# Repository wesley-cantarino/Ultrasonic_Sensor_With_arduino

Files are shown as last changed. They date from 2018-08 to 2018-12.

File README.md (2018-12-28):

## Ultrasonic Sensor With arduino

Este projeto marca a minha transição entre projetos físicos para software pois depois desse projeto eu passei a interessar muito mais na área de programação. Foi aqui que eu conheci uma das melhores linguagens de programação, [Processing <3.](https://processing.org/)

Obs: a documentação encontra-se dentro das pastas do respectivo ano.

## 2017

#### Começo

Precisava fazer um trabalho final para curso de programação física codeIOT. Pensando nisso, eu já estava trabalhando a vários dias  na tentativa de fazer um carrinho de controle remoto (mais tarde descobri que as baterias que eu estava usando e também o transmissor são de baixa qualidade). Visto que não ia conseguir terminar devido a problemas técnicos (hehe). Resolvi então partir para radar ultrassônico.

#### Motivação

Inspirado [neste projeto (how to mechatronics )](http://howtomechatronics.com/projects/arduino-radar-project/) resolvi criar a minha própria versão mas usando 2 ultrassônico.

Realmente ficaram muito parecidos:
* how to mechatronics
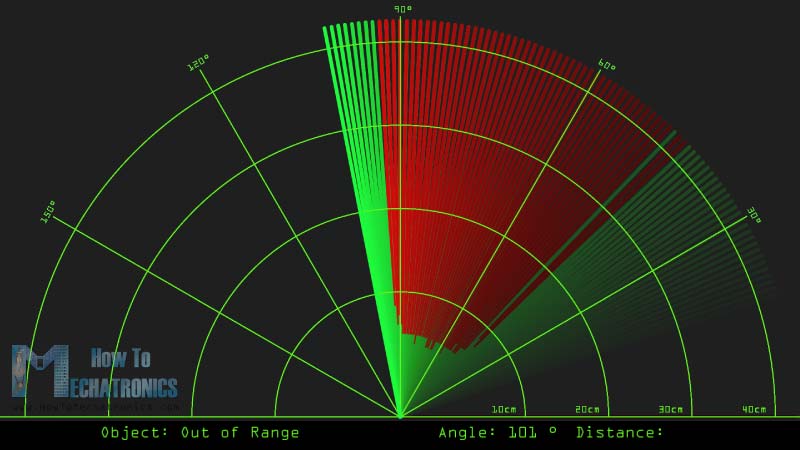
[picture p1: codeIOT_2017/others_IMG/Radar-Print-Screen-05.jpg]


* Minha versão
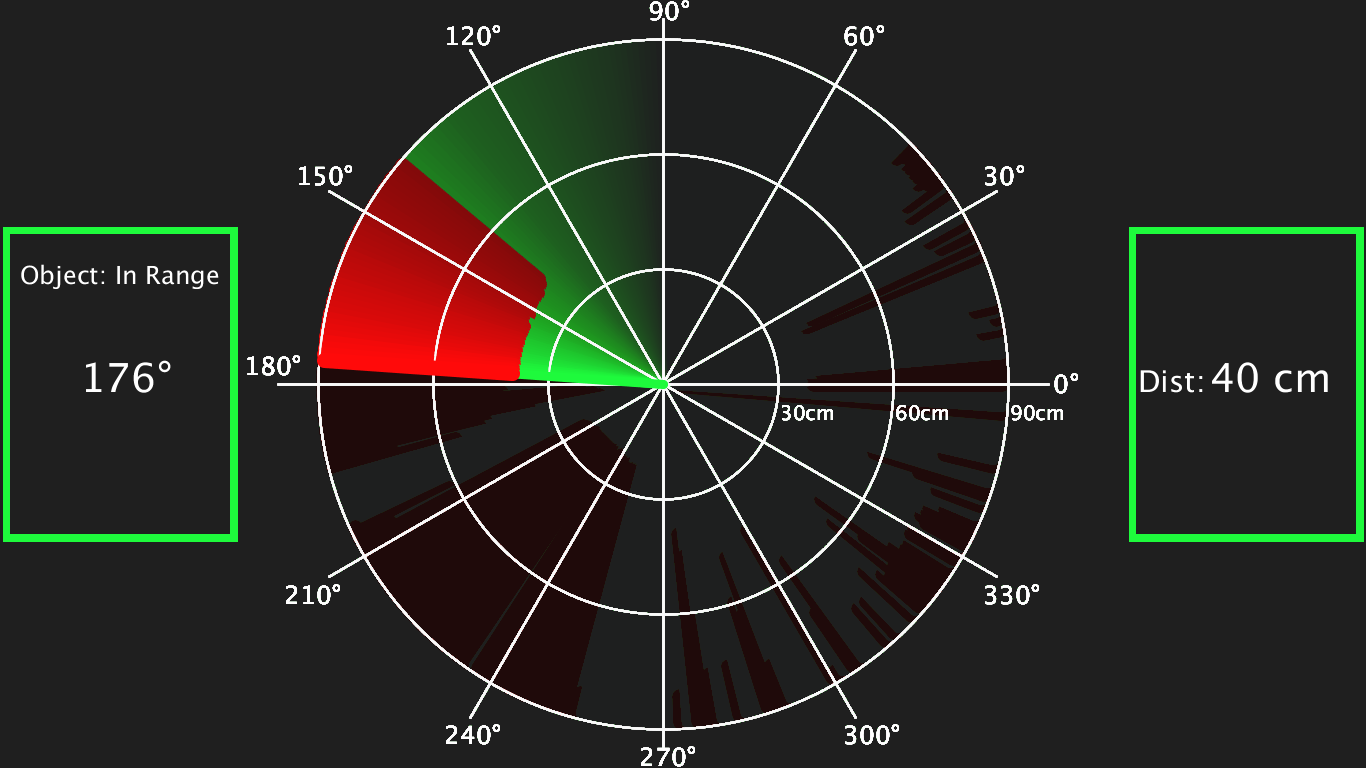
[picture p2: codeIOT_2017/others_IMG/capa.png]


Foi neste projeto que passei a estudar Processing mais a sério.

## 2018

Agora, o foco foi em software. A comunicação sem fio foi retirada e oque antes era em um disco (ou seja, no plano) agora em no IR^3 (ou seja, no espaço tridimensional).

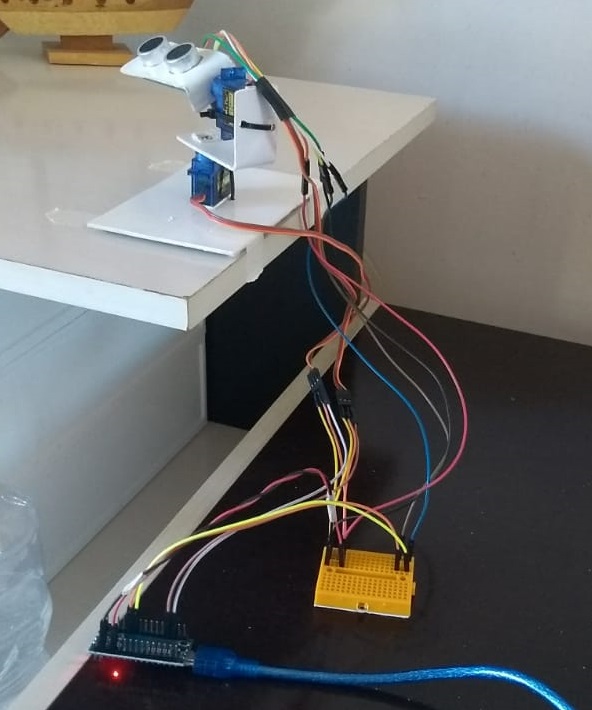
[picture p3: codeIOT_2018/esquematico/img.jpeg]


Menu principal do programa

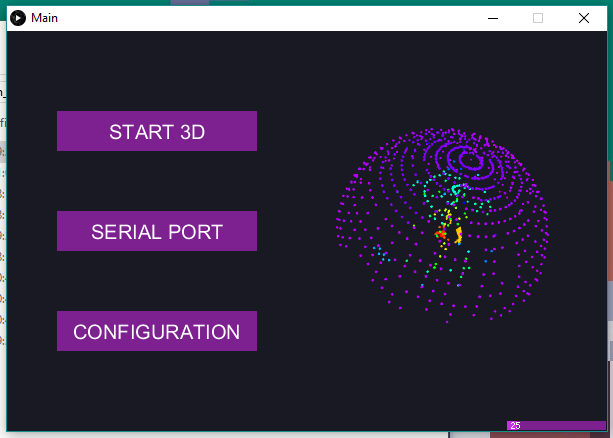
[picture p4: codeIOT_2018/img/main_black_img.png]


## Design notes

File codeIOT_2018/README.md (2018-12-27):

* Obs: Falta fazer documentação decente pois o arquivo codeIOT_2018.pdf está bem fraquinho.

#### [Certificado :D <3](http://codeiot.org.br/certificates/13802e48f1b748a4ace83a3f53ac93c5)

<hr>

### Explicação rápida


A montagem é simples :)

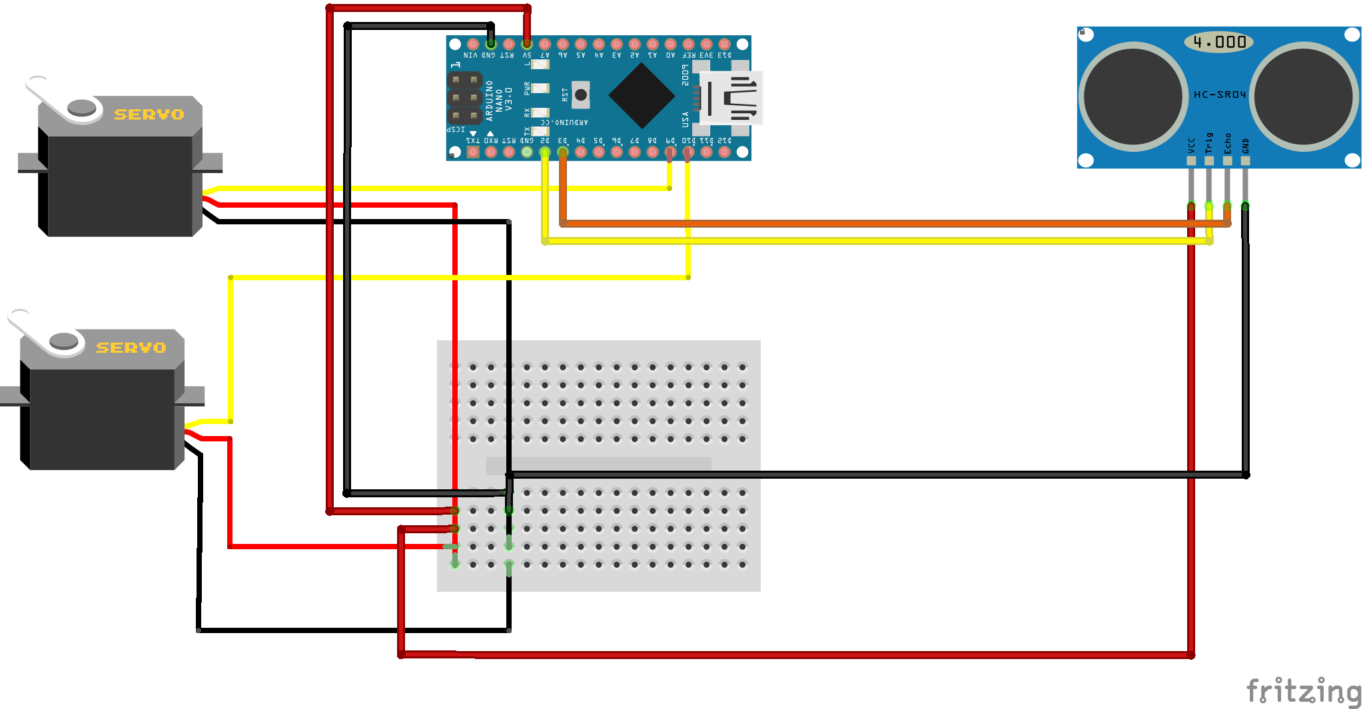
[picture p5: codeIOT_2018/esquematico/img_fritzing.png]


Para quem já estudou mudança de coordenadas na resolução de integrais tripas já sacou que essa montagem é perfeita para coordenadas polares

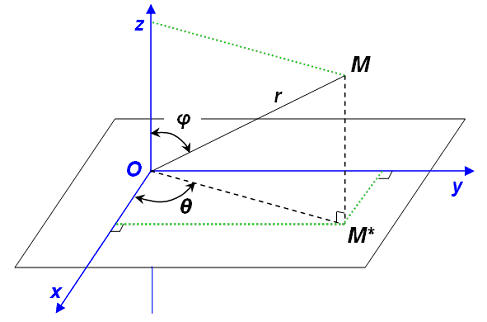
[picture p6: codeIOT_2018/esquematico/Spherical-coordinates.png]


#### Onde
* r é a distancia medida pelo sensor.
* teta e fi são os ângulos dos servos

### Minha tentativa de criar interface gráfica para usuário :D

Menu principal:
 


Temos também o tema claro (essa cor se aplica a todas as outras abas):

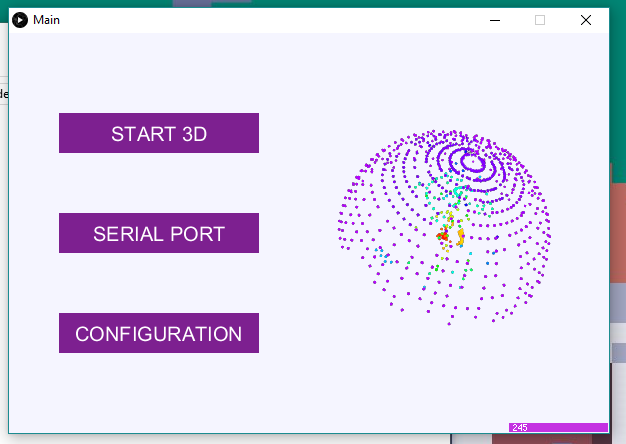
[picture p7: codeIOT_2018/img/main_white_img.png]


<hr>
Aba Configurações 

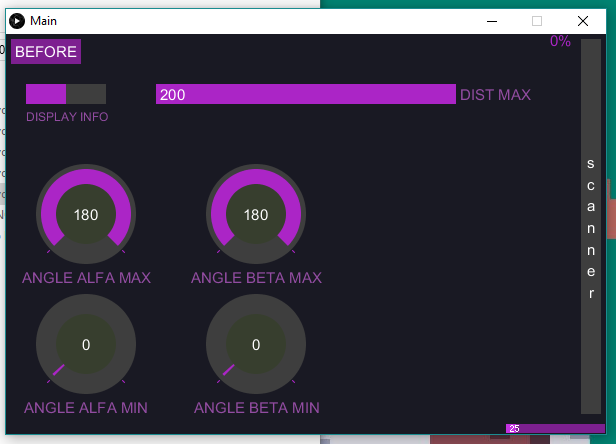
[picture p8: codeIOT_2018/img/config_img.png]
Configurações


<hr>
Aba seleção de porta serial

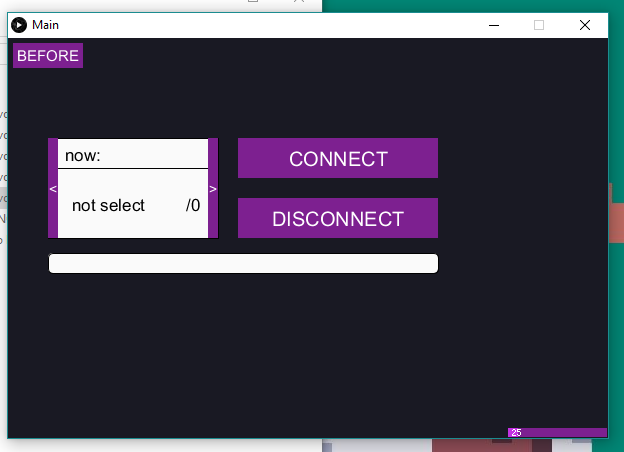
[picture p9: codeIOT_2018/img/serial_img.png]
porta serial


<hr>
* Certamente esse projeto foi de maior complexidade. Perceba a evolução de um ano para o outro.

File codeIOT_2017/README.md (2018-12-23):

* ### Em [proj-Sonar.pdf](https://github.com/wesley-cantarino/Ultrasonic_Sensor_With_arduino/blob/master/codeIOT_2017/proj-Sonar.pdf) tempos toda a documentação mais bem detalhada.

* Dentro da pasta RX_files temos imagem do projeto, Fritzing e o code. Mesma coisa para TX_files

* #### [Certificado :D <3](http://codeiot.org.br/certificates/cbcd800a2408466495cf4520fc58f5d8)

<hr>

### Explicação rápida

* #### Tx
São 2 servos motores de rotação de 180º cobindo assim 360º. O sensor ultrassônico faz leitura da distância e o arduino o envia para Rx.
Se chama Tx pois esse sistema envia dados.

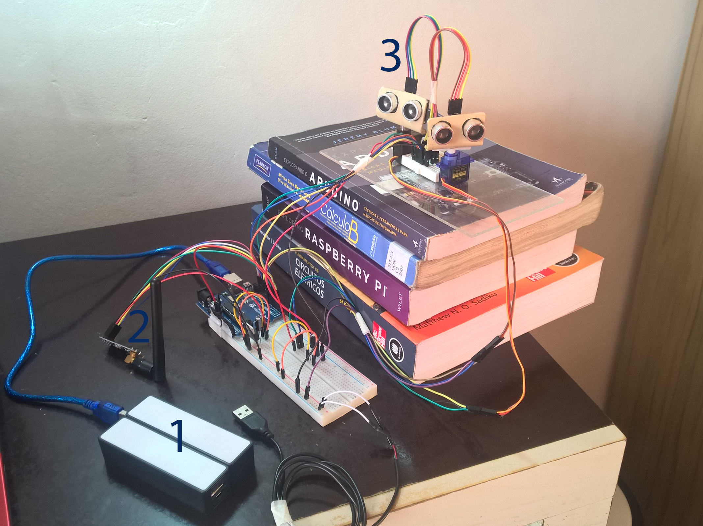
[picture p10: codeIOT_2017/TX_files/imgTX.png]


* #### Rx
Composto por apenas a antena. Esse sistema é responsável por enviar os dados recebido para o computador atravez da porta serial.
Se chama Rx pois esse sistema recebe dados.

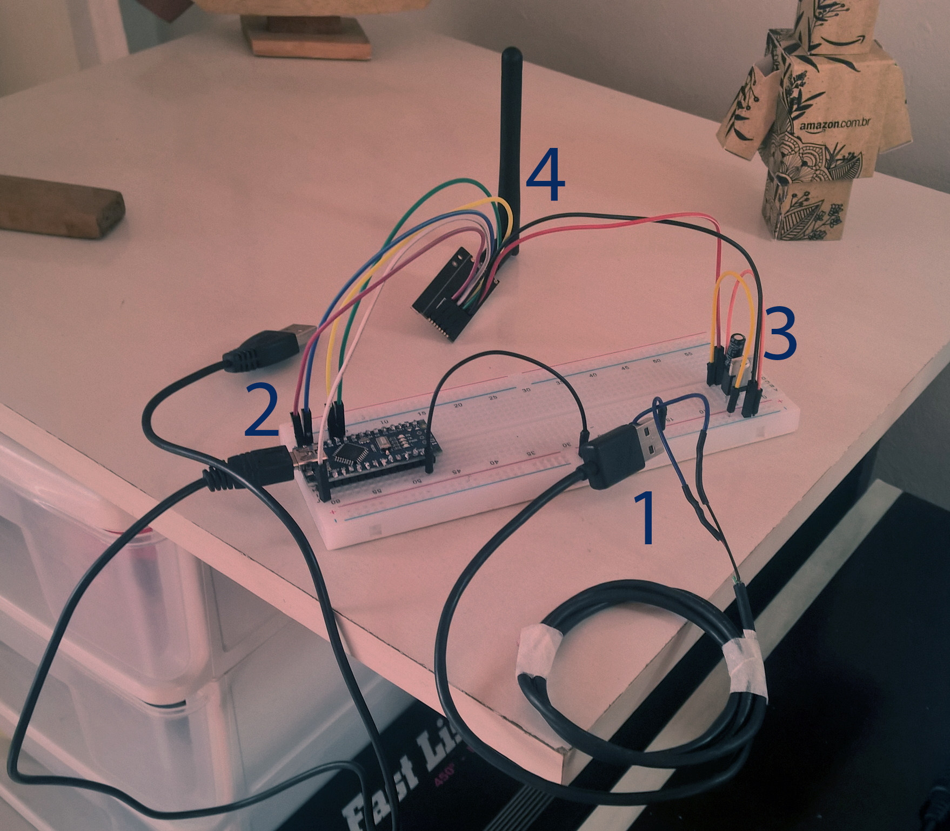
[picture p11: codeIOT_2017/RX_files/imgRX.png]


* #### Processing
Por último o processing vai fazer leitura desses dados na porta serial e vai fazer a parte gráfica. Tendo como resultado isso :)


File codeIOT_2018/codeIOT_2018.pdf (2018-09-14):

# Radar 3D

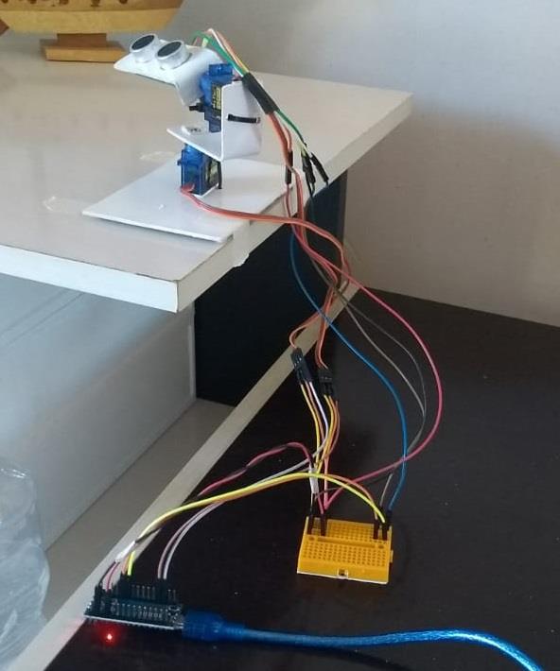
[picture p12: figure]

- Vídeo aqui (vejam pfv): https://youtu.be/GHxOZZLBg7I
- Código aqui: (https://github.com/wesley-cantarino/Ultrasonic_Sensor_With_arduino/tree/master/codeIOT_2018) https://github.com/wesleycantarino/Ultrasonic_Sensor_With_arduino/tree/master/codeIOT_2018
- Não vou apresentar os componentes pois eles já foram apresentados ao longo do curso e também não vou apresentar o código da interface gráfica pois é bem extenso mas para quem tiver curiosidade esta comentado no github.

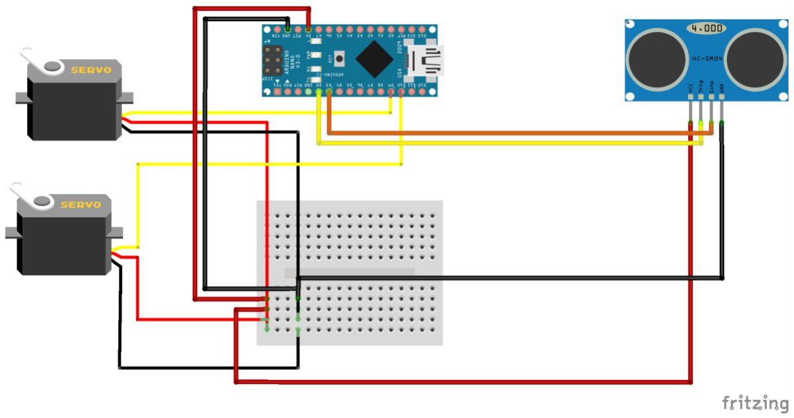
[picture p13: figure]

- Interface gráfica feita com amo <3 usando processing (https://processing.org/).
- A ideia aqui é como gerar imagens de objetos no 3D.
- 2 Servos de 0º a 180º, sensor ultrassônico e arduino nano.
- Coordenada esféricas em cartesianas r é a distância que o sensor ultrassônico medir
0º <= teta <= 180º em relação ao plano XY.
0º <= fi <= 180º em relação perpendicular ao plano XY.

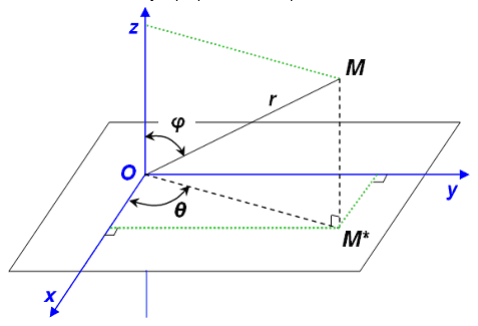
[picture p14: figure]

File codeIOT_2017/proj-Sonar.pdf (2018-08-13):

# SONAR COM ARDUINO

# USANDO IDE PROCESSING E RADIOFREQUÊNCIA

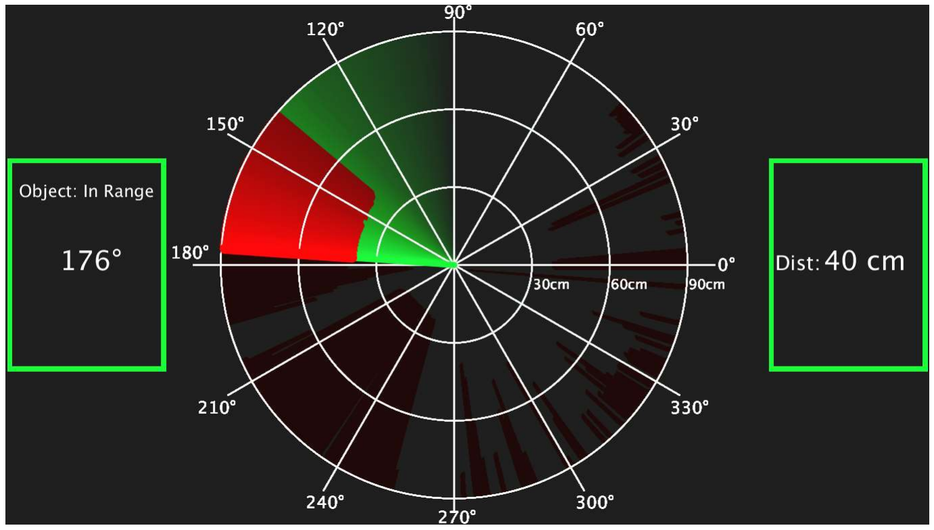
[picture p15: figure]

1

# Sumário

2

# Introdução

O projeto consiste em girar o sensor ultrassônico usando um servo no ângulo de 0 a 180 graus então trocar para o outro servo e girar o outro sensor ultrassônico de 180 a 360 graus totalizando uma volta completa. O ultrassônico tem um alcance de 2 cm a 400 cm mais no processing foi programado para só exibir no “mapa” de 2 cm à 90 cm o motivo dessa escolha foi para não ficar em uma escala muito grande priorizando assim a riqueza de detalhes.
Após o arduino (TX ou seja o transmissor) mover o servo e calcular a distância pelo ultrassônico então chega na melhor parte. A transmissão sem fio! Usando NRF24L01 com antena externa (importante lembrar que este módulo não segue o protocolo IEEE 801.11 então não vai se comunicar com WIFI do roteador ou do celular apesar de trabalhar na mesma frequência). O TX envia a informação (ângulo e distância) o RX (receptor) recebe e envia para o computador através da porta serial. Então os dados são interpretados pelo IDE processing que move a barra verde e desenha a barra vermelha de acordo com o ângulo e a distância recebida. Link para o vídeo mostrando o projeto: https://www.youtube.com/watch?v=B4Q-fz4psLs

# Montagem

## Imagem do RX (receptor):

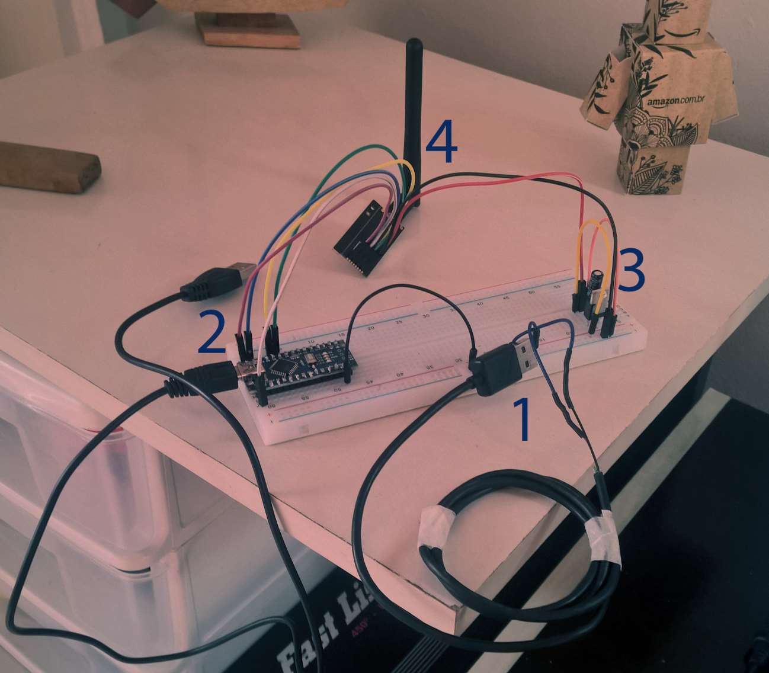
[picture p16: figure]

## Esquema de ligação usando o fritzing:

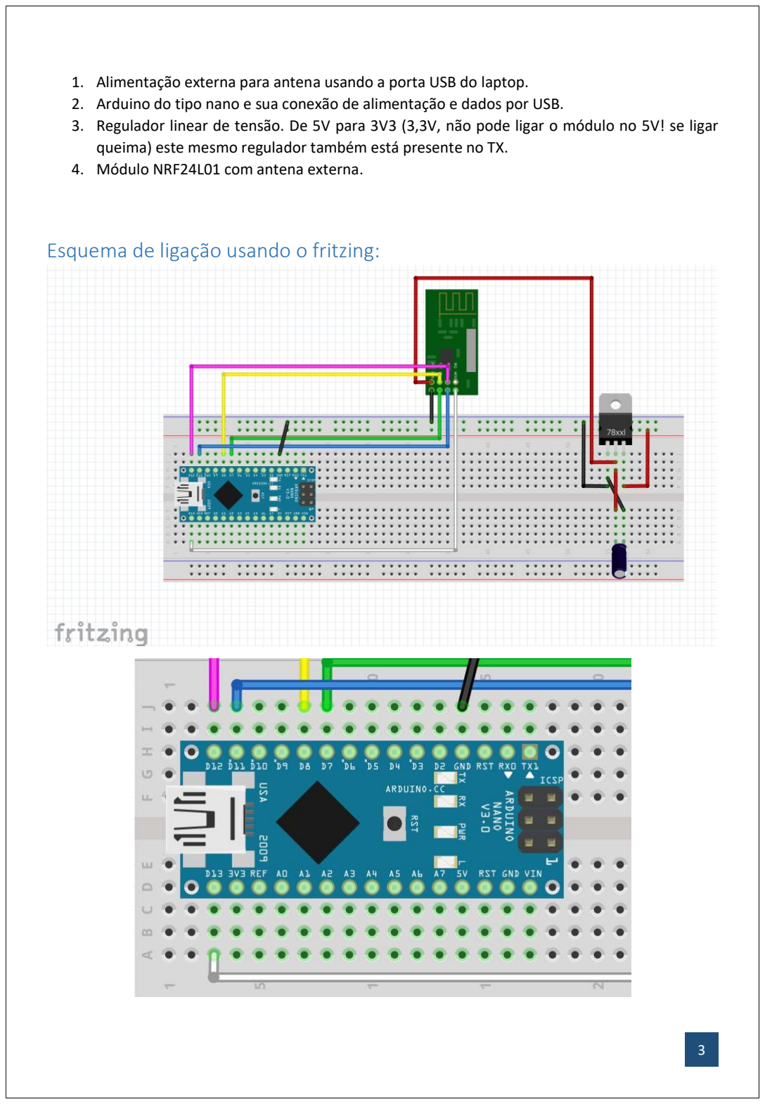
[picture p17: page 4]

3

1. Alimentação externa para antena usando a porta USB do laptop.
2. Arduino do tipo nano e sua conexão de alimentação e dados por USB.
3. Regulador linear de tensão. De 5V para 3V3 (3,3V, não pode ligar o módulo no 5V! se ligar queima) este mesmo regulador também está presente no TX.
4. Módulo NRF24L01 com antena externa.

4

Observação:

- Apesar de esta escrito na imagem do regulador de tensão 78xxl na verdade é um LD1117V.
- A foto é uma versão mais antiga do NRF24L01 mas o esquema de ligação é o mesmo. Ficar atento quanto a ligação no módulo (nome do pino).

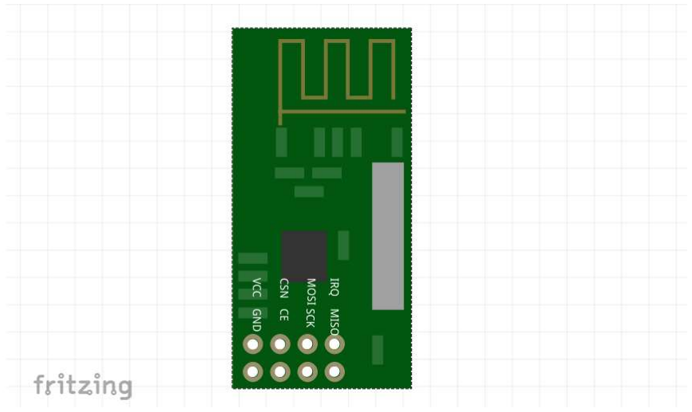
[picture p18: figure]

Sobre o módulo NRF24L01.
- VCC é para ligar 3V3. A corrente pode chegar a 115mA no modo transmissão então optei por fazer uma alimentação externa.
- GND é o negativo.
- CE e CSN são pinos de controle. Pode ligar em qualquer pino digital eu escolhi os pinos 7 e 8 para CE e CSN respectivamente.
- SCK, MOSI e MISO são comunicação SPI então deve ser ligado em pinos específicos (11, 12 e 13 respectivamente).
- IRQ não será usado.
- Link para o datasheet do produto em inglês: https://www.nordicsemi.com/chi/content/download/2730/34105/file/nRF24L01_Product_Specification_v2_0.pdf

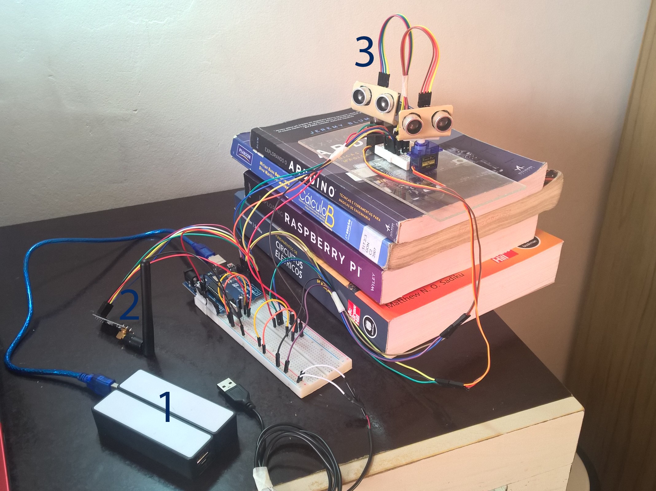
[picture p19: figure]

5

Agora para o TX

## Imagem do TX (transmissor):

1. Dois power bank.
2. Mesmo módulo NRF24L01 do RX.
3. Dois servos e Dois sensores ultrassônicos.
A novidade no TX é o power bank, a troca do arduino nano por um uno, sevos e os ultrassônicos. A montagem do NRF24L01 é exatamente a mesma do RX. A pilha de livros é para os ultrassônicos não detectarem o próprio cabo.

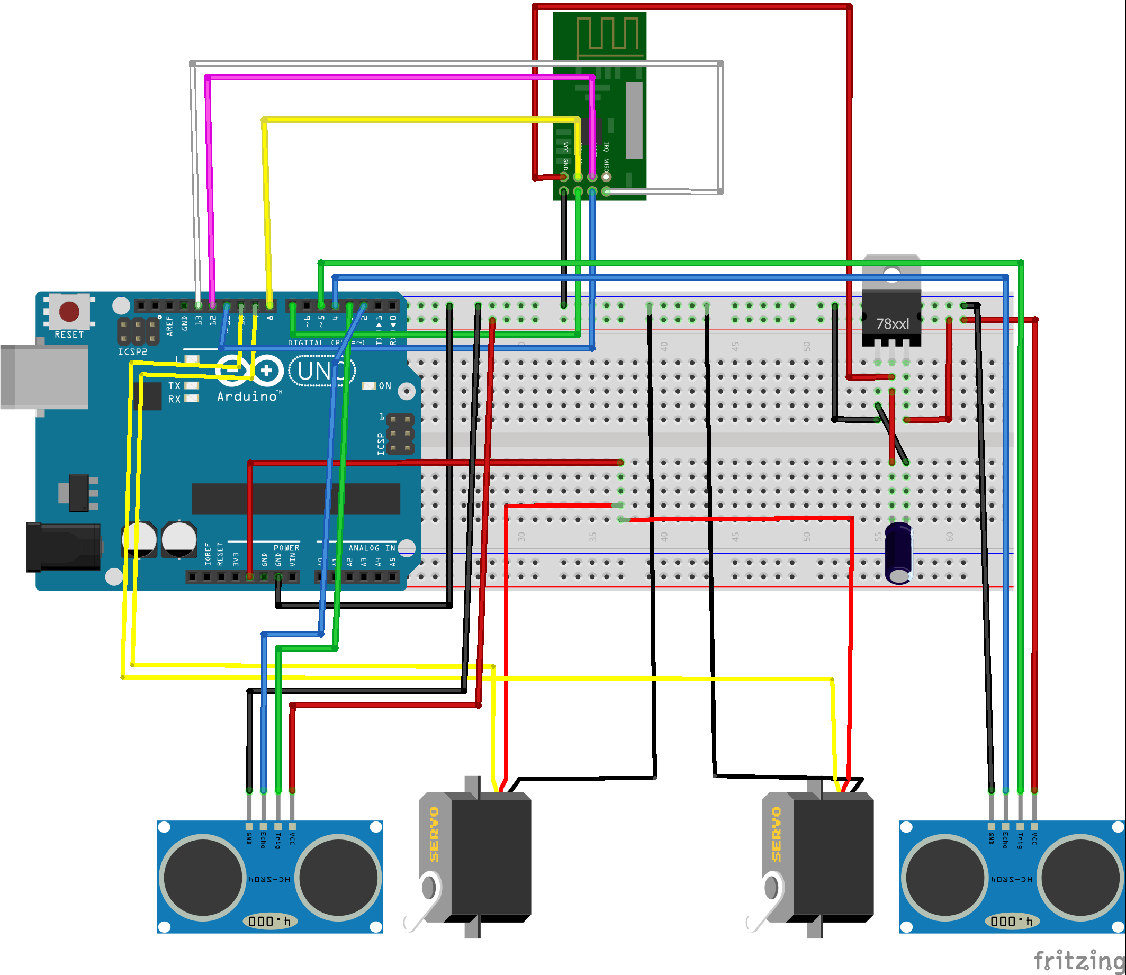
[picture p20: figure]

6

## Esquema de ligação usando o fritzing:

Não esqueça que na trilha de energia (positiva e negativa) está ligada em um dos power bank. datasheet:
Servo https://cdn.instructables.com/ORIG/FA2/O1SS/J7ARLNBW/FA2O1SSJ7ARLNBW.pdf ultrassônico https://www.mpja.com/download/hc-sr04_ultrasonic_module_user_guidejohn.pdf

Eu recomendo a leitura dos datasheet para um melhor entendimento.

7

# Código

Download da biblioteca nRF24L01.h https://drive.google.com/file/d/0BxP9TuJ18bsFenBjbDRqWkIwZ1E/view

Para o RX https://drive.google.com/open?id=0BxP9TuJ18bsFMnJpbjdmc0JFVG8
1 | #include <SPI.h> | //bibliotecas
2 #include "nRF24L01.h"
3 #include "RF24.h"
4
5 | int DICE[2]; | //vetor para armazenar os dados recebidos
6
7 | RF24 radio(7,8); | // CE; CSN
8
9 | const byte address[6] = "00001"; | //canal de comunicação. Tem que ser igual ao do TX
10

### 11 void setup(void){

12 Serial.begin(9600); | //comunicação serial
13 | radio.begin(); | //liga o modulo RX

### 14 radio.openReadingPipe(0, address); //define como leitura o canal

15 | radio.setPALevel(RF24_PA_HIGH); | //potência da antena
16 radio.startListening(); | //fica pronto para receber dados
17 }
18

### 19 void loop(void){

20 if ( radio.available() ){ | //verifica se tem dados
21 | //teste(); | //para teste do módulo
22
23 | radio.read( DICE, sizeof(DICE) ); | //faz leitura dos dados recebidos e armazena em DICE
24 Serial.print(DICE[0]); | //imprime na porta serial o ângulo
25 Serial.print(",");
26 Serial.print(DICE[1]); | //imprime na porta serial a distancia
27 | Serial.print("."); | //tirar ln
28
29 }
30 }
31

### 32 int teste(){

33 radio.read( DICE, sizeof(DICE) ); 34
35 Serial.print(DICE[0]);
36 Serial.print(" ");
37 Serial.println(DICE[1]); 38 }

8

Para o TX https://drive.google.com/open?id=0BxP9TuJ18bsFZm1pYXJJbE5RLXM 1 #include <SPI.h>
2 #include "nRF24L01.h"
3 #include "RF24.h"
4 #include <Servo.h>
5 #define ANmax 180 //angulo maximo 6 #define ANmin 0 //angulo minimo 7 Servo Servo1;
8 Servo Servo2;
9

### 10 const int SERVO1 = 10; //azul 11 const int SERVO2 = 9; //preto

12
13 const int trigPin = 3;
14 const int echoPin = 2;
15 const int trigPin2 = 5; 16 const int echoPin2 = 4; 17 long duration;
18 float distance;
19
20 int DICE[2];
21 RF24 radio(7,8);
22 const byte address[6] = "00001"; 23

### 24 void setup(void){

25 Servo1.attach(SERVO1);
26 Servo2.attach(SERVO2);
27 pinMode(trigPin, OUTPUT); 28 pinMode(trigPin2, OUTPUT);
29 Serial.begin(9600);
30 radio.begin();
31 | radio.openWritingPipe(address); | //escreve os dados nesse canal
32 radio.setPALevel(RF24_PA_MIN); //potência se colocar maior a antena desliga. Não sei o motivo
33 | radio.stopListening(); | //para transmitir
34 }
35

### 36 void loop(){

37 //teste();
38 for(int a = 0; a <= 180; a++){ | //move o servo 1 e usar o ultrassônico 1
39 Servo1.write(a);
40 delay(15);
41 DICE[0] = a;
42 DICE[1] = funDIST1();
43 radio.write( DICE, sizeof(DICE) ); 44 }

9

45

### 46 for(int a = 1; a <= 180; a++){

48 Servo2.write(a);
49 delay(15);
50 DICE[0] = a + 180;
51 DICE[1] = funDIST2();
52 radio.write( DICE, sizeof(DICE) ); 53 }
54 }
55

### 56 int teste(){

57 DICE[0] = 1;
58 DICE[1] = 4;
59 radio.write( DICE, sizeof(DICE) ); 60 delay(50);
61 }
62
63 float funDIST1(){ | //eu sei que existe biblioteca para isso

### 64 digitalWrite(trigPin, LOW); //mas tava dando 10 cm a mais do que a distância real

65 delayMicroseconds(2);
66 digitalWrite(trigPin, HIGH);
67 delayMicroseconds(10);
68 digitalWrite(trigPin, LOW);
69 duration = pulseIn(echoPin, HIGH); 70 distance= duration*0.034/2;
71 distance = constrain(distance, 2, 400); 72 return distance;
73 }
74

### 75 float funDIST2(){

76 digitalWrite(trigPin2, LOW); 77 delayMicroseconds(2);
78 digitalWrite(trigPin2, HIGH);
79 delayMicroseconds(10);
80 digitalWrite(trigPin2, LOW);
81 duration = pulseIn(echoPin2, HIGH); 82 distance= duration*0.034/2;
83 distance = constrain(distance, 2, 400); 84 return distance;
85 }

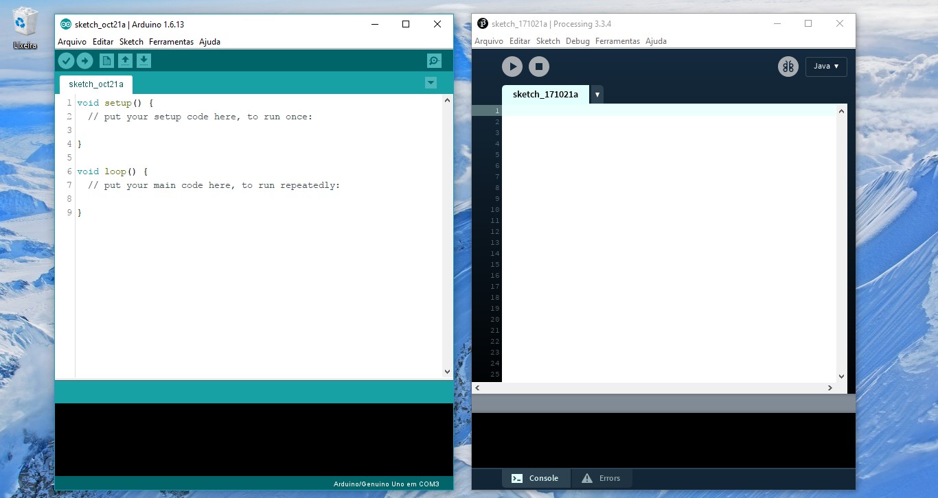
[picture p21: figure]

10

## O processing

O processing é uma linguagem gráfica, open source. Assim como quase todas as linguagens de programação essa também tem comunicação serial. Então por que usar processing? Resposta é, Fácil de programar. A IDE (Ambiente de desenvolvimento integrado) é parecida com a IDE do arduino. Aliais o arduino foi inspirado no processing

Notou alguma semelhança?
Download do processing pode ser feito nesse link: https://processing.org/download/
Para quem quiser aprender detalhes das funções basta acessar https://processing.org/reference/ e procurar a função.
Observação: Quando eu ia copilar o código (apertar o play) tinha que copilar e colocar a porta USB (que está ligada no arduino RX) quase ao mesmo tempo.

## Vamos para o código:

Eu testei em uma tela (1366, 766) em fullscreen. Não sei dizer o que acontece em outras resoluções.

https://drive.google.com/open?id=0BxP9TuJ18bsFRFdlSnFJNE5OckE

11

1 import processing.serial.*;
2 import java.io.IOException;

### 3 import java.awt.event.KeyEvent; 4

5 Serial myPort;
6 PImage img;
7 String angle="";
8 String distance="";
9 String data="";
10 String noObject;
11 float pixsDistance;
12 int iAngle, iDistance;
13 int index1=0;
14 int index2=0;
15

### 16 void setup(){

17 //size(1360,760); | //Tamanho da tela
18 | fullScreen(); | //Tela toda
19 smooth();
20 myPort = new Serial(this, "COM4", 9600); 21 myPort.bufferUntil('.');
22 background(100, 200, 100);
23 }
24
25

### 26 void draw(){

27 noStroke();
28 fill(0,4);
29 rect(0, 0, width, height-height*0.00001); 30 fill(98,245,31);
31
32 drawRadar();
33 drawLine();
34 //iDistance = 67; //para teste 35 drawObject();
36 drawText();
37 }
38
39

### 40 void serialEvent (Serial myPort) {

41 data = myPort.readStringUntil('.');
42 data = data.substring(0,data.length()-1); 43
44 index1 = data.indexOf(",");
45 angle= data.substring(0, index1);
46 distance= data.substring(index1+1, data.length());

12

47
48 iAngle = int(angle);
49 iDistance = int(distance); 50 }
51
52

### 53 void drawRadar() {

54 pushMatrix();

### 55 translate(663, 384); //centro

56 noFill();
57 strokeWeight(2);
58 | stroke(250,250,250); | //Branco
59
60 // draws the arc lines
61 arc(0,0,690,690,PI,2*TWO_PI);
62 arc(0,0,460,460,PI,2*TWO_PI); 63 arc(0,0,230,230,PI,2*TWO_PI); 64

### 65 stroke(250,250,250); //Branco

66
67 // draws the angle lines
68 line(-385,0,385,0);
69
70 line(385*cos(radians(30)),385*sin(radians(30)),-385*cos(radians(30)),-385*sin(radians(30)));
71 line(385*cos(radians(60)),385*sin(radians(60)),-385*cos(radians(60)),-385*sin(radians(60)));
72 line(+385*cos(radians(120)),+385*sin(radians(120)),-385*cos(radians(120)),-385*sin(radians(120))); 73 line(+385*cos(radians(150)),+385*sin(radians(150)),-385*cos(radians(150)),-385*sin(radians(150))); 74
75 line(0,-365,0,365);
76 popMatrix();
77 }
78

### 79 void drawLine(){

80 pushMatrix();
81 strokeWeight(9);
82 | stroke(30,250,60); | //verde
83 translate(663, 384); | //centro
84 line(0,0,(height-height*0.558)*cos(radians(iAngle)),-(height-height*0.558)*sin(radians(iAngle))); 85 popMatrix();
86 }
87

### 88 void drawObject() {

89 pushMatrix();

### 90 translate(663, 384); // moves the starting coordinats to new location

91 strokeWeight(15);

### 92 stroke(255,10,10); // red color

13

93
94 | pixsDistance = iDistance*((height-height*0.558)/90); | // O max que pixsDistance pode ir é 500!!!
95 //X = (height-height*0.558) / 90
96

### 97 if(iDistance <= 90){

98 //line(500*cos(radians(iAngle)),-500*sin(radians(iAngle)),pixsDistance*cos(radians(iAngle)),-pixsDistance*sin(radians(iAngle)));
99 line(pixsDistance*cos(radians(iAngle)),-pixsDistance*sin(radians(iAngle)), (height-height*0.558)*cos(radians(iAngle)), -(height-height*0.558)*sin(radians(iAngle))); 100 //line(x1,y1,x2,y2);
101 }
102 popMatrix();
103 }
104
105 void drawText() {
106 stroke(30,250,60);
107 pushMatrix();
108 fill(98,245,31);
109 rect(10,234,220,300);
110 rect(1136,234,220,300); 111 noStroke();
112 fill(31,31,31);
113 rect(10,234,220,300);
114 rect(1136,234,220,300); 115
116 if(iDistance > 90) {
117 noObject = "> 90cm";
118 }
119 else {
120 noObject = "In Range";
121 }
122
123 fill(255,255,255); //color white 124 textSize(25);
125 text("Object: " + noObject,20,284); 126 textSize(40);
127 text("" + iAngle +"°", 80,392);
128
129 textSize(30);
130 text("Dist: ", 1138,392);
131 textSize(40);
132 text("" + iDistance +" cm", 1210, 392); 133
134 textSize(20);
135 text("30cm",780,420);
136 text("60cm",895,420);
137 text("90cm",1010,420);

14

138
139 //fill(98,245,60); //verde 140 fill(255,255,255); //branco 141 textSize(25);
142
143 translate(663, 384);
144 text("0°",390,9);
145 resetMatrix();
146
147 translate(663, 384);
148 text("180°",-420,-10); 149 resetMatrix();
150
151 translate(663, 384);
152 text("90°",-16,-365);
153 resetMatrix();
154
155 translate(663, 384);
156 text("270°",-25,382);
157 resetMatrix();
158
159 translate(663, 384);
160 text("30°",320,-200);
161 resetMatrix();
162
163 translate(663, 384);
164 text("150°",-368,-200); 165 resetMatrix();
166
167 translate(663, 384);
168 text("210°",-380,220); 169 resetMatrix();
170
171 translate(663, 384);
172 text("330°",320,220);
173 resetMatrix();
174
175 translate(663, 384);
176 text("60°",180,-340);
177 resetMatrix();
178
179 translate(663, 384);
180 text("120°",-220,-340); 181 resetMatrix();
182

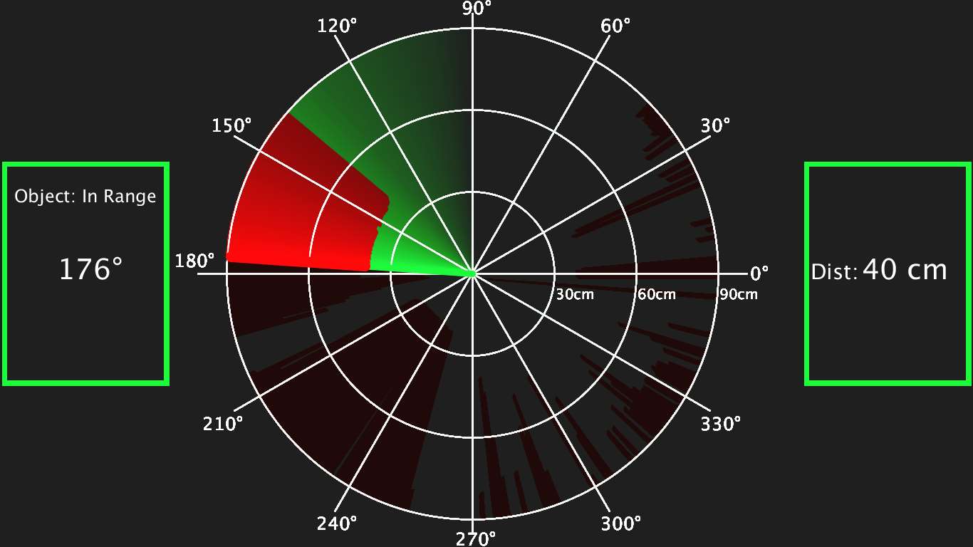
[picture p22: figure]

15

183 translate(663, 384);
184 text("240°",-220,360); 185 resetMatrix();
186
187 translate(663, 384);
188 text("300°",180,360);
189 resetMatrix();
190
191 popMatrix();
192 }
193 //UFA!!

Após copilar vai exibir uma janela parecida com a da imagem abaixo.

- “Object: in Range” quer dizer tem algo dentro do raio de 90 cm.
- 176º é o ângulo em que se encontra o servo.
- “Dist: 40 cm” é que tem algum objeto a 40 cm do sensor ultrassônico

16

# Conclusão

O sensor ultrassônico tem que emitir o som (é trabalho do trigger), Desliga e então escutar (é trabalho do echo). O tempo em que o som viaja e volta faz com que o código fique mais lendo ou mais rápido. Mudando a velocidade angular média. Uma solução boa para manter a velocidade do algoritmo constante seria substituir o ultrassônico por um sensor sharp IR. Porém teremos novos problemas.
Primeiramente, O preço. Sensores sharp custam em média 10 dólares. O alcance é outro problema, um sensor sharp de 20 dólares tem alcance de 20 a 150 cm enquanto o ultrassônico que encontra em lojas brasileiras com preço entorno de R$8 a R$13 tem alcance de 2cm a 400cm. Última coisa que queria dizer é a montagem pode até parecer simples, mas muitas vezes tudo travava ai era aquela dificuldade em saber onde estava o erro. As vezes o erro estava no código as vezes na montagem mais na maioria dos casos eu não sabia onde estava.
No projeto inicial era de colocar esse projeto em um carrinho. Porém, estava dando muito erro ao tentar ligar os motores DC e acabei desistindo. Espero que esse trabalho inspire vocês a montarem e modificarem seus projetos. Caso alguém queira entrar em contato meu email é “wesley.cantarino@engenharia.ufjf.br”.

Inspirações:

http://howtomechatronics.com/projects/arduino-radar-project/ acesso: 21/10/2017 http://howtomechatronics.com/tutorials/arduino/arduino-wireless-communication-nrf24l01-tutorial/ acesso: 21/10/2017

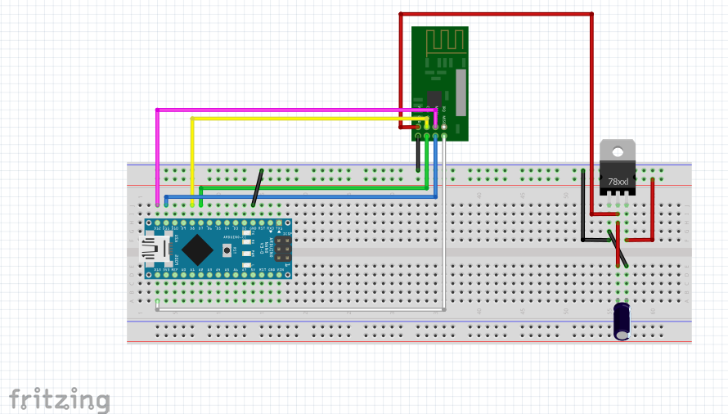
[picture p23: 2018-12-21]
codeIOT_2017/RX_files/imgRXfritzing.png

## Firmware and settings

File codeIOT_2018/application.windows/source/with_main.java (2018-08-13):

import processing.core.*; 
import processing.data.*; 
import processing.event.*; 
import processing.opengl.*; 

import controlP5.*; 
import processing.serial.*; 
import peasy.*; 

import java.util.HashMap; 
import java.util.ArrayList; 
import java.io.File; 
import java.io.BufferedReader; 
import java.io.PrintWriter; 
import java.io.InputStream; 
import java.io.OutputStream; 
import java.io.IOException; 

public class with_main extends PApplet {


ControlP5 main_button;
ControlP5 slider_color;
ControlP5 before;
ControlP5 conf;

int sliderValue = 25;
boolean display_dist = true;
int dist_max = 200;
int angle_alfa_max, angle_alfa_min, angle_beta_max, angle_beta_min;

ControlP5 comand_serial_port;

PImage main_photo;

ChildApplet windows_star_3d;
boolean windows_star_3d_open = false;
int alfa, beta;

boolean play_button_2 = false;
boolean play_button_3 = false;


Serial myPort;
int transX = 50;
int transY = 100;
int select = 0;
int selectAUX = 0;
String conect_now = "";
boolean conect = false;
boolean go = false;

public void settings (){
  size(600, 400);
}

public void setup (){
  surface.setTitle("Main");

  colorMode(HSB);
  main_photo = loadImage("main_photo.png");
  main_button = new ControlP5(this);
  slider_color = new ControlP5(this);
  before = new ControlP5(this);
  comand_serial_port = new ControlP5(this);
  conf = new ControlP5(this);

  create_button();
}

public void draw (){
  colorMode(RGB);
  background(sliderValue, sliderValue, sliderValue + 10);
  colorMode(HSB);

  if (play_button_2){
    before.setVisible(true);
    comand_serial_port.setVisible(true);
    main_button.setVisible(false);
    conf.setVisible(false);

    serial_port();
  }

  else if (play_button_3){
    before.setVisible(true);
    conf.setVisible(true);
    comand_serial_port.setVisible(false);
    main_button.setVisible(false);

    configuration();
  }

  else{
    before.setVisible(false);
    conf.setVisible(false);
    comand_serial_port.setVisible(false);
    main_button.setVisible(true);

    image(main_photo, 270, 62);
  }
}

public void button1 (){
  if(!windows_star_3d_open){
    windows_star_3d = new ChildApplet();
    windows_star_3d_open = true;
  }
}

public void button2 (){
  play_button_2 = true;
  play_button_3 = false;
}

public void button3 (){
  play_button_3 = true;
  play_button_2 = false;
}

public void before (){
  play_button_3 = false;
  play_button_2 = false;
}

public void connect (){
  if((select != 0) && (!conect)){
    myPort = new Serial(this, Serial.list()[select - 1], 115200);
    myPort.bufferUntil(';');
    conect_now = Serial.list()[select - 1];
    conect = true;
    selectAUX = select;
    go = true;
  }

  if((conect) && (select != selectAUX) && (select != 0)){
    myPort.stop();
    myPort = new Serial(this, Serial.list()[select - 1], 115200);
    myPort.bufferUntil(';');
    conect_now = Serial.list()[select - 1];
    selectAUX = select;
    go = true;
  }
}

public void disconnect (){
  if(conect){
    conect = false;
    conect_now = "";
    myPort.stop();
  }
}

public void plus_left (){
  select -= 1;
}

public void plus_right (){
  select += 1;
}

public void create_button (){
  slider_color.addSlider("sliderValue")
              .setLabel("")
              .setPosition(width - 100, height - 10)
              .setRange(0, 245)
              .setColorBackground(0xff7d2090)
              .setColorForeground(0xffc432e2)
              .setColorActive(0xff4a1255);

  before.addButton("before")
        .setPosition(5, 5)
        .setSize(70, 25)
        .setFont(createFont("Arial", 15))
        .setColorBackground(0xff7d2090)
        .setColorForeground(0xffc432e2)
        .setColorActive(0xff4a1255);

  main_button.addButton("button1")
             .setLabel("Start 3D")
             .setPosition(50, height/4 - 20)
             .setSize(200, 40)
             .setColorLabel(0xffffffff)
             .setFont(createFont("Arial", 20))
             .setColorBackground(0xff7d2090)
             .setColorForeground(0xffc432e2)
             .setColorActive(0xff4a1255);

  main_button.addButton("button2")
             .setLabel("Serial port")
             .setPosition(50, height/2 - 20)
             .setSize(200, 40)
             .setColorLabel(0xffffffff)
             .setFont(createFont("Arial", 20))
             .setColorBackground(0xff7d2090)
             .setColorForeground(0xffc432e2)
             .setColorActive(0xff4a1255);

  main_button.addButton("button3")
             .setLabel("configuration")
             .setPosition(50, height - height/4 - 20)
             .setSize(200, 40)
             .setColorLabel(0xffffffff)
             .setFont(createFont("Arial", 20))
             .setColorBackground(0xff7d2090)
             .setColorForeground(0xffc432e2)
             .setColorActive(0xff4a1255);

  comand_serial_port.addButton("connect")
                    .setPosition(180 + transX, 0 + transY)
                    .setSize(200, 40)
                    .setColorLabel(0xffffffff)
                    .setFont(createFont("Arial", 20))
                    .setColorBackground(0xff7d2090)
                    .setColorForeground(0xffc432e2)
                    .setColorActive(0xff4a1255);

  comand_serial_port.addButton("disconnect")
                    .setPosition(180 + transX, 60 + transY)
                    .setSize(200, 40)
                    .setColorLabel(0xffffffff)
                    .setFont(createFont("Arial", 20))
                    .setColorBackground(0xff7d2090)
                    .setColorForeground(0xffc432e2)
                    .setColorActive(0xff4a1255);

  comand_serial_port.addButton("plus_left")
                    .setLabel("<")
                    .setPosition(-10 + transX, transY)
                    .setSize(10, 100)
                    .setColorLabel(0xffffffff)
                    .setFont(createFont("Arial", 14))
                    .setColorBackground(0xff7d2090)
                    .setColorForeground(0xffc432e2)
                    .setColorActive(0xff4a1255);

  comand_serial_port.addButton("plus_right")
                    .setLabel(">")
                    .setPosition(150 + transX, transY)
                    .setSize(10, 100)
                    .setColorLabel(0xffffffff)
                    .setFont(createFont("Arial", 14))
                    .setColorBackground(0xff7d2090)
                    .setColorForeground(0xffc432e2)
                    .setColorActive(0xff4a1255);

  conf.addToggle("display_dist")
      .setLabel("display info")
      .setPosition(20, 50)
      .setSize(80, 20)
      .setMode(Toggle.SWITCH)
      .setColorLabel(0xff924ca1)
      .setFont(createFont("Arial", 12))
      .setColorBackground(0xff3e3e3e)
      .setColorActive(0xffab25c6);

  conf.addSlider("dist_max")
      .setCaptionLabel("dist max")
      .setPosition(150, 50)
      .setSize(300, 20)
      .setRange(2, 200)
      .setValue(200)
      .setFont(createFont("Arial", 15))
      .setColorLabel(0xff924ca1)
      .setColorBackground(0xff3e3e3e)
      .setColorForeground(0xffab25c6)
      .setColorActive(0xffc432e2);

  conf.addKnob("angle_alfa_max")
      .setLabel("angle alfa max")
      .setPosition(30, 130)
      .setSize(100, 15)
      .setRange(0, 180)
      .setValue(180)
      .setFont(createFont("Arial", 15))
      .setColorLabel(0xff924ca1)
      .setColorBackground(0xff3e3e3e)
      .setColorForeground(0xffab25c6)
      .setColorActive(0xffc432e2);

  conf.addKnob("angle_beta_max")
      .setLabel("angle beta max")
      .setPosition(200, 130)
      .setSize(100, 15)
      .setRange(0, 180)
      .setValue(180)
      .setFont(createFont("Arial", 15))
      .setColorLabel(0xff924ca1)
      .setColorBackground(0xff3e3e3e)
      .setColorForeground(0xffab25c6)
      .setColorActive(0xffc432e2);

  conf.addKnob("angle_alfa_min")
      .setLabel("angle alfa min")
      .setPosition(30, 260)
      .setSize(100, 15)
      .setRange(0, 180)
      .setValue(0)
      .setFont(createFont("Arial", 15))
      .setColorLabel(0xff924ca1)
      .setColorBackground(0xff3e3e3e)
      .setColorForeground(0xffab25c6)
      .setColorActive(0xffc432e2);

  conf.addKnob("angle_beta_min")
      .setLabel("angle beta min")
      .setPosition(200, 260)
      .setSize(100, 15)
      .setRange(0, 180)
      .setValue(0)
      .setFont(createFont("Arial", 15))
      .setColorLabel(0xff924ca1)
      .setColorBackground(0xff3e3e3e)
      .setColorForeground(0xffab25c6)
      .setColorActive(0xffc432e2);
}
public void configuration (){
  fill(0xff3e3e3e);
  noStroke();
  textAlign(CENTER, CENTER);
  textSize(15);

  rect(575, 5, 20, 375);

  float perct = map(alfa, 0, 180, 0, 375);
  int perct_100 = PApplet.parseInt(map(perct, 0, 375, 0, 100));

  fill(0xffab25c6);
  rect(575, 5, 20, perct);
  text(perct_100 + "%", 555, perct + 5);

  fill(0xffffffff);
  text("s\nc\na\nn\nn\ne\nr", 585, 192);

  fill(0xff924ca1);
  if ((angle_alfa_min > angle_alfa_max) ||
     ((angle_beta_min > angle_beta_max)))
    text("angle min do not can > angle max", 165, 110);
}
public void serial_port (){
  pushMatrix();
    translate(transX, transY);
    fill(250);
    stroke(0);
    textSize(17);
    textAlign(CENTER, CENTER);

    rect(-10, 0, 170, 100);
    rect(-10, 115, 390, 20, 5, 5, 5, 5);
    line(0, 30, 150, 30);

    fill(0);
    text("now:", 25, 15);

    draw_dice();

    textSize(12);
    text("<", -5, 50);
    text(">", 155, 50);
  popMatrix();
}

public void draw_dice (){
  int tam = Serial.list().length;

  if(tam == 0)
    select = 0;

  if(select > tam)
    select = 0;

  if(select < 0)
    select = tam;

  text("/" + tam, 135, 65);

  int i = 0;
  while(i < tam){
    text(Serial.list()[i], 25 + i*60, 123);
    i ++;
  }

  if(select != 0)
    text(Serial.list()[select - 1], 30, 65);
  else
    text("not select", 50, 65);

  text(conect_now, 85, 15);
}
class ChildApplet extends PApplet {
  public ChildApplet() {
    super();
    PApplet.runSketch(new String[]{this.getClass().getName()}, this);
  }

  
  PeasyCam cam;

  /*-------------------------------*/
  String one ="";
  String dado ="";
  String data="";
  int index1=0;

  int tipo, DADO;
  /*-------------------------------*/
  float dist;

  float [] alfa_DB = new float [931];
  float [] beta_DB = new float [931];
  float [] dist_DB = new float [931];
  float [] dice_x = new float [931];
  float [] dice_y = new float [931];
  float [] dice_z = new float [931];
  float [] colores = new float [931];

  int number = 0;
  /*-------------------------------*/

  public void settings (){
    size(1024, 600, P3D);
    smooth(3);
  }

  public void setup (){
    surface.setTitle("Graf 3D");

    colorMode(HSB);
    fill(255);
    noStroke();
    lights();

    cam = new PeasyCam(this, width);
    cam.setMinimumDistance(50);
    cam.setMaximumDistance(5000);

    if ((Serial.list().length != 0) && (!conect)){
      myPort = new Serial(this, Serial.list()[0], 115200);
      myPort.bufferUntil(';');
      go = true;
      conect_now = Serial.list()[0];
    }
  }

  public void draw() {
    if(go){
      while(myPort.available() > 0){
        data = myPort.readStringUntil(';');
        data = data.substring(0, data.length()-1);

        index1 = data.indexOf(",");
        one = data.substring(0, index1);
        dado = data.substring(index1+1, data.length());

        tipo = PApplet.parseInt(one);
        DADO = PApplet.parseInt(dado);

        if(tipo == 1){
          alfa = DADO;
          alfa_DB[number] = alfa;
        }

        if(tipo == 2){
          beta = DADO;
          beta_DB[number] = beta;
        }

        if(tipo == 3){
          dist = 2 * DADO;

          dist_DB[number] = dist/2;
          dice_x[number] = dist * cos(radians(alfa)) * cos(radians(beta));
          dice_y[number] = dist * cos(radians(alfa)) * sin(radians(beta));
          dice_z[number] = dist * sin(radians(alfa));

          colores[number] = map(dist/2, 2, 200, 0, 200);
          number++;
        }
      }
    }

    colorMode(RGB);
    background(sliderValue, sliderValue, sliderValue + 10);
    colorMode(HSB);

    fill(255);
    sphere(5);
    for(int i = 0; i < number; i++){
      if((dist_max >= dist_DB[i]) &&
         (alfa_DB[i] <= angle_alfa_max) &&
         (angle_alfa_min <= alfa_DB[i]) &&
         (beta_DB[i] <= angle_beta_max) &&
         (angle_beta_min <= beta_DB[i]))
      {
        pushMatrix();
          translate(dice_x[i], dice_y[i], dice_z[i]);
          fill(colores[i], 255, 255);
          sphere(5);
        popMatrix();
      }
    }

    if(display_dist){
      fill(0xffffffff);
      stroke(0xffffffff);
      line(0, 0, 0, 430, 0,   0);
      text("X", 430, 0, 0);
      line(0, 0, 0, 0, 430,   0);
      text("Y", 0, 430, 0);
      line(0, 0, 0, 0,   0, 430);
      text("Z", 0, 0, 430);
      noStroke();

      int k = 0;
      int kk = 0;
      textSize(40);
      textAlign(RIGHT, CENTER);

      for(int i = 0; i < 20; i++){
        pushMatrix();
          translate(k - 400, 500);
          fill(map(i, 0, 19, 0, 200), 255, 255);
          k += 40;
          box(40);
          if(i % 2 == 0){
            text(PApplet.parseInt(map(i, 0, 19, 2, 200)), kk - 20, 50);
            kk += 10;
          }
          popMatrix();
      }
    }
  }
}
  static public void main(String[] passedArgs) {
    String[] appletArgs = new String[] { "with_main" };
    if (passedArgs != null) {
      PApplet.main(concat(appletArgs, passedArgs));
    } else {
      PApplet.main(appletArgs);
    }
  }
}

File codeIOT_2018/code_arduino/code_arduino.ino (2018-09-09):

#include <Servo.h>
#include <Ultrasonic.h>

/*-----------SERVO-----------*/
const int Ser1 = 9; //angle alpha servo cabeca
Servo ser1;

const int Ser2 = 10; //angle beta servo base
Servo ser2;
/*---------------------------*/

/*-----------ULTRA-----------*/
#define TRIGGER_PIN  2
#define ECHO_PIN     3

Ultrasonic ultrasonic(TRIGGER_PIN, ECHO_PIN);

float dist;
long times;
/*---------------------------*/

int down_alfa, down_beta, down_delay = 500;
boolean down = false;

int beta_min = 70, beta_max = 110;
int alfa_min = 0, alfa_max = 45;
/*---------------------------*/

void processing (int alfa, int beta){
  Serial.print("1");
  Serial.print(",");
  Serial.print(alfa);
  Serial.print(";");

  Serial.print("2");
  Serial.print(",");
  Serial.print(beta);
  Serial.print(";");

  Serial.print("3");
  Serial.print(",");
  //dist = k;
  Serial.print(dist);
  Serial.print(";");
}

void calcDIST (){
  times = ultrasonic.timing();
  dist = ultrasonic.convert(times, Ultrasonic::CM);
  dist = constrain(dist, 2, 400);
}

void go (int alfaAUX, int betaAUX, int tempo){
  int beta = beta_min;

  for(int alfa = alfa_min; alfa <= alfa_max; alfa = alfa + alfaAUX){
    alfa = constrain(alfa, alfa_min, alfa_max);
    ser1.write(alfa);

    if(alfa != 90){
      if(beta <= beta_min){
        while(beta <= beta_max){
          beta = constrain(beta, beta_min, beta_max);
          ser2.write(beta);
          delay(tempo);

          calcDIST();
          processing(alfa, beta);

          beta = beta + betaAUX;
        }
      }
      else {
        while(beta >= beta_min){
          beta = constrain(beta, beta_min, beta_max);
          ser2.write(beta);
          delay(tempo);

          calcDIST();
          processing(alfa, beta);

          beta = beta - betaAUX;
        }
      }
    }
  }
}

void setup (){
  Serial.begin(115200);

  ser1.attach(Ser1);
  ser2.attach(Ser2);

  //max and min
  Serial.print("4");
  Serial.print(",");
  Serial.print(alfa_min);
  Serial.print(";");

  Serial.print("5");
  Serial.print(",");
  Serial.print(alfa_max);
  Serial.print(";");

  Serial.print("6");
  Serial.print(",");
  Serial.print(beta_min);
  Serial.print(";");

  Serial.print("7");
  Serial.print(",");
  Serial.print(beta_max);
  Serial.print(";");
}

void leitura (){
  if (Serial.available() > 0){
    delay(100);

    while(Serial.available() > 0){
      down_alfa = Serial.read();
      down_beta = Serial.read();
      //down_delay = Serial.read(); //esta com erro

      down = true;
    }
  }
}

void loop (){
  leitura();

  if (down == true){
    Serial.print("8");
    Serial.print(",");
    Serial.print("1");
    Serial.print(";");

    go(down_alfa, down_beta, down_delay);
    /*down_delay = 1000;
    ser1.write(down_alfa);
    delay(down_delay);
    ser1.write(0);
    delay(down_delay);

    ser2.write(down_beta);
    delay(down_delay);
    ser2.write(0);
    delay(down_delay);*/

    down = false;
    Serial.print("8");
    Serial.print(",");
    Serial.print("0");
    Serial.print(";");
  }
}
